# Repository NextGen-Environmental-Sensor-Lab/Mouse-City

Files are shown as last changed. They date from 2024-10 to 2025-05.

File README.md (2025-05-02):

# Mouse-City
Welcome to the NextGen Environmental Sensor Lab's Mouse City. We aim to simulate a city environment using urban sounds and various light patterns. This repository is currently incomplete but feel free to use the information available.

For any questions and concerns please file an issue through the issue tab. We'll try to resolve the issue as soon as possible!

Mouse City's core circuit components are a WeMos D1 Mini and a Audio FX Sound Board (from Adafruit). Additional contents of the circuit can be found in the [BOM](https://github.com/NextGen-Environmental-Sensor-Lab/Mouse-City/blob/main/BOM.md)  above. The BOM of the full circuit is located there as well.

 

## Content
### Arduino
* Required Libraries and Boards
* Code Contents
### Audio Tracks
* Audio File Type
* Converter
### Mouse City Circuit 
* Parts List
### Node-Red
* Node Function and Use

## Arduino IDE
To use the code in the [Arduino](https://github.com/NextGen-Environmental-Sensor-Lab/Mouse-City/tree/main/Arduino/CityMouseLight_Sound) folder the user needs to install the Adafruit Neopixel library and the esp8266 (by ESP8266 Community) board manager.
Once installed the code can be used. 

Note: The board used from this board manager is the "WEMOS D1 MINI ESP32".

Also Note: Our code is a modified version of the Adafruit Neopixel strandtest example. This can be seen where we use the theaterchase function to rotate the lights around the LED strip.

Code Contents: Our code contains multiple functions to control audio, speaker volume, and LED strip function. 

Note: Our code only recognizes predetermined commands. Unknown commands will be ignored.
* Audio: Sound() Where each input calls the selected audio track to play. There are 4 pins available, but only 3 are in use here.
* Volume: Volume() Where each input increases of decreases the volume.
* LED Strip: theaterChase() Where each input decides the pattern of the LED Strip for about 20 seconds.

## Audio Tracks 
To use the Sound() function the Arduino Soundboard needs at least one audio track. These tracks must be wav files. If the files you intend to use are different you can convert them. The converter we used is [cloud convert](https://cloudconvert.com/mp3-to-wav). 

Note: The soundboard only accepts 8 or 16 bit wav files. (The higher the bit the better the audio sounds). Also mono files compared to stero files are smaller in size allowing for less storage consumption. 

## Mouse City Circuit 
### Parts List

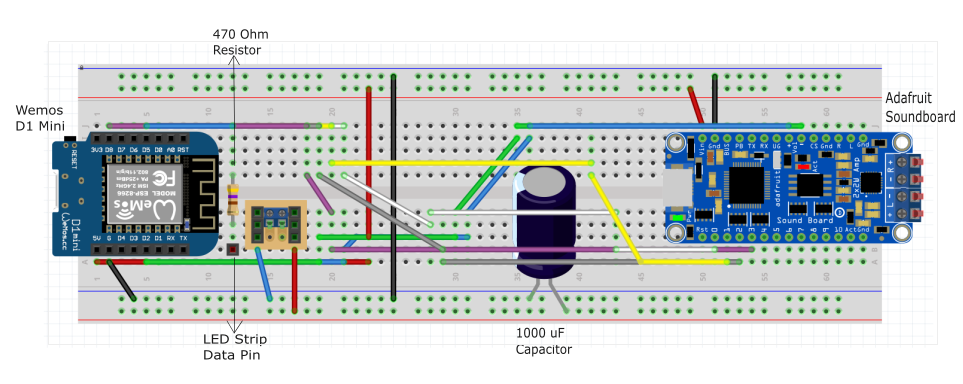
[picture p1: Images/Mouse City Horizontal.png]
 

| Part Name | Part Image | Purchase Link|
|---|---|:---:|
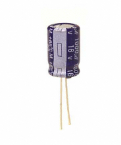
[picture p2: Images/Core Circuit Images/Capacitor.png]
|1000 µF Capacitor|  |[Digikey](https://www.digikey.com/en/products/detail/panasonic-electronic-components/ECA-1CM102B/8603353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)
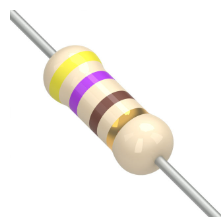
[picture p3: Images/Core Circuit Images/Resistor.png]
|470 Ohm Resistor|  |[Digikey](https://www.digikey.com/en/products/detail/koa-speer-electronics,-inc./CF1%2F4C471J/13537235?utm_adgroup=General&utm_source=google&utm_medium=cpc&utm_campaign=PMax%20Shopping_Product_Zombie%20SKUs&utm_term=&utm_content=General&utm_id=go_cmp-17815035045_adg-_ad-__dev-c_ext-_prd-13537235_sig-Cj0KCQjwjNS3BhChARIsAOxBM6pdZWOkhexXrhcUmCtDRSBonp6of6M5_js4P4ElzA45IlZfCEqIjtQaAlmEEALw_wcB&gad_source=1&gclid=Cj0KCQjwjNS3BhChARIsAOxBM6pdZWOkhexXrhcUmCtDRSBonp6of6M5_js4P4ElzA45IlZfCEqIjtQaAlmEEALw_wcB)
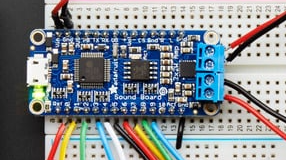
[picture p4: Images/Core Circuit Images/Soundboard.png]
|Adafruit Audio FX Sound Board|  |[Adafruit](https://www.adafruit.com/product/2217)
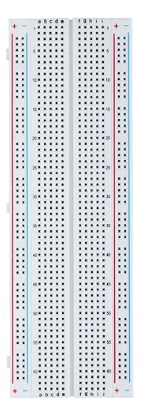
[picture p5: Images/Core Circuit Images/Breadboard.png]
|Breadboard|  |[Amazon](https://www.amazon.com/EL-CP-003-Breadboard-Solderless-Distribution-Connecting/dp/B01EV6LJ7G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)
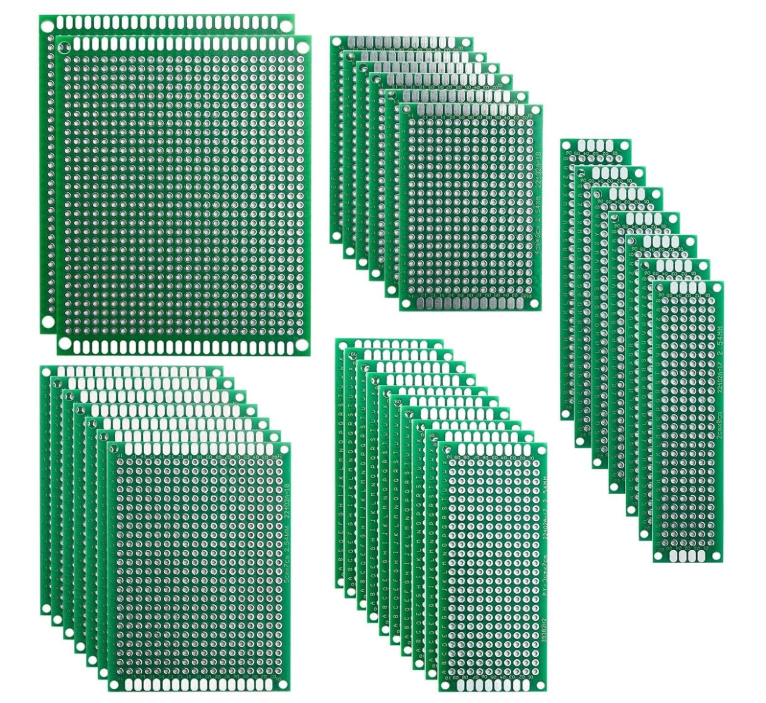
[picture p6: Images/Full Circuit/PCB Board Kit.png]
|ELEGOO PCB Board Kit|  |[Amazon](https://www.amazon.com/ELEGOO-Prototype-Soldering-Compatible-Arduino/dp/B072Z7Y19F)
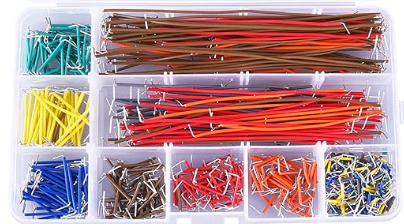
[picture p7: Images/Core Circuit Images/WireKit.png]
|Jumper Wire Kit|  |[Amazon](https://www.amazon.com/AUSTOR-Lengths-Assorted-Preformed-Breadboard/dp/B07CJYSL2T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)
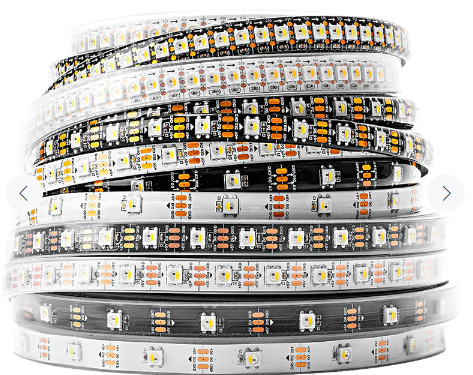
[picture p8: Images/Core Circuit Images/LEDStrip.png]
|LED Strip (White)|  |[BTF Lighting](https://www.btf-lighting.com/products/1-sk6812-rgbw-4-in-1-pixels-individual-addressable-led-strip-dc5v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)
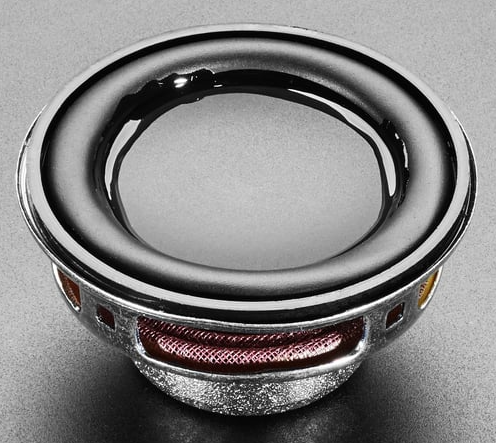
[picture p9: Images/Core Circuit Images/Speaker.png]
|Speaker - 40mm Diameter - 4 Ohm 5 Watt|  |[Adafruit](https://www.adafruit.com/product/3968)
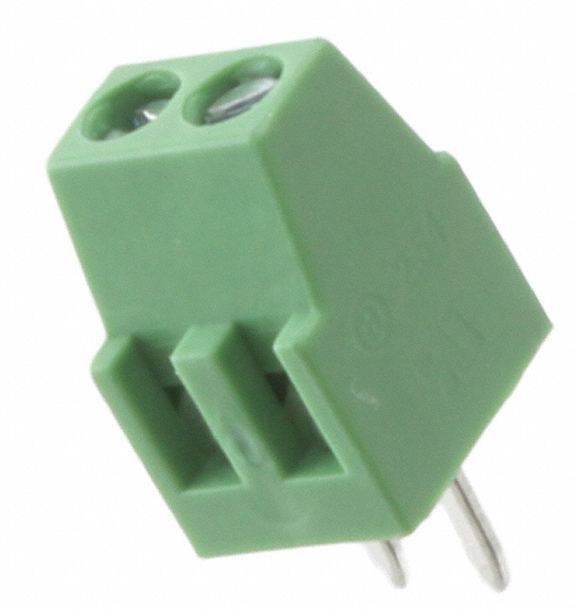
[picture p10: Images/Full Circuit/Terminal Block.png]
|Terminal Blocks|  |[Digikey](https://www.digikey.com/en/products/detail/qualtek/311007-01/183390)
|WeMos D1 Mini (Microcontroller)|  |[Amazon](https://www.amazon.com/dp/B0BR9GBNZH?ref=fed_asin_title)

### Important Note!!
Running the LED Strip and Voltage Supply through the bread board will cause a short circuit. To avoid this we suggest a spliced connection between the power supply, LED strip, and terminal block.

## Node-Red
Node-Red is a low-level coding program that visualizes code. We use it to automate the scheduling of our lights and audio. This was done through the use of different blocks of code Node-Red calls 'nodes'. The collection of these nodes are known as 'flows'.

Getting started with Node-Red. All information on setting up Node-Red can be found [here](https://nodered.org/docs/getting-started/) for new users.

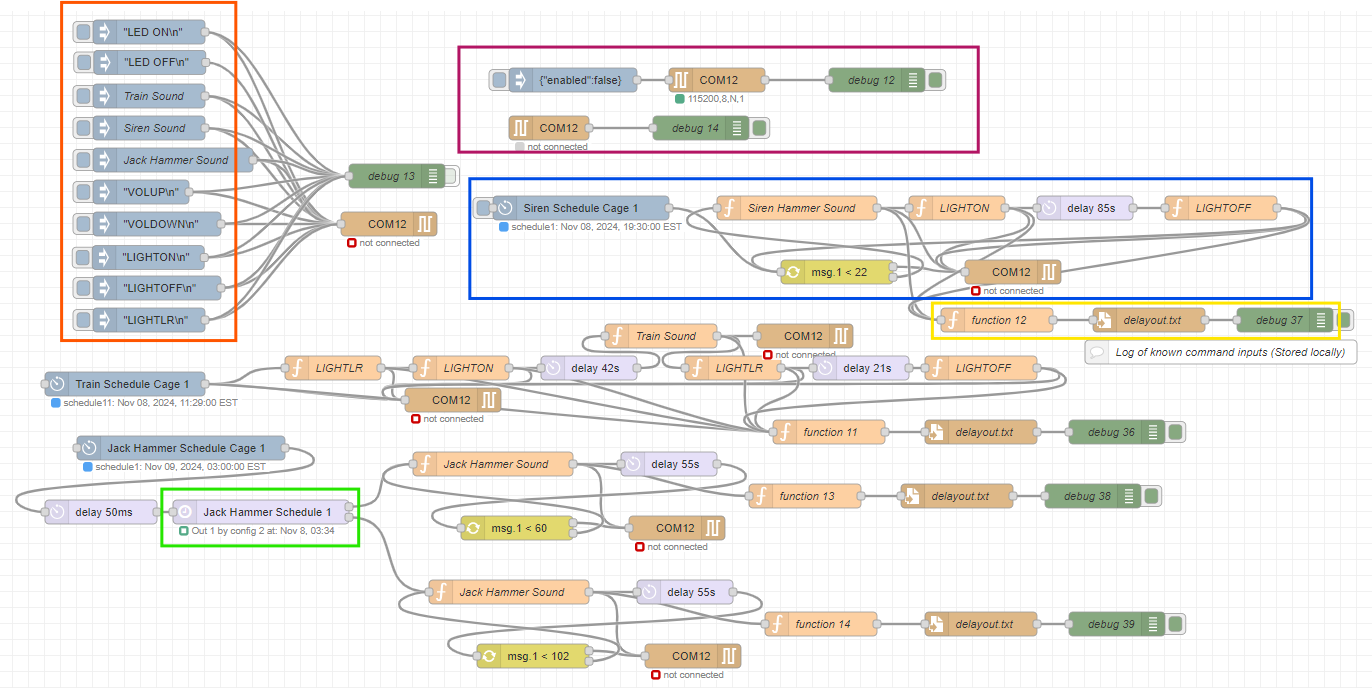
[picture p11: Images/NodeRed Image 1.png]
 

* Node Function:
    * The orange box displays all of the known commands our code will accept. These nodes inject/input the stated commands into the WeMos D1 Mini.
    
        Note: The commands for Sounds (Train, Siren, and Jack Hammer) are "PLAY0\n", "PLAY1\n", and "PLAY2\n" respectively. 
    * The purple box outputs information the serial port receives by use of the debug and serial port nodes. It also allows the user to disconnect from the serial port by injecting a "false".
    * The blue box contains the schedule for one of our audio tracks and lights. At a specified time set in the blue inject node (cronplus) the lights and sound play. The lights and sound are looped by the msg. node to play x amount of times that the user chooses.
    * The yellow box makes a local text file logging the inputs to the system.
    * The green box is a special scheduler (timegate) that allows two different action to take place based at the time they received.

Note: All NodeRed flows can be accessed [here](https://github.com/NextGen-Environmental-Sensor-Lab/Mouse-City/tree/main/Node%20Red%20Flows).

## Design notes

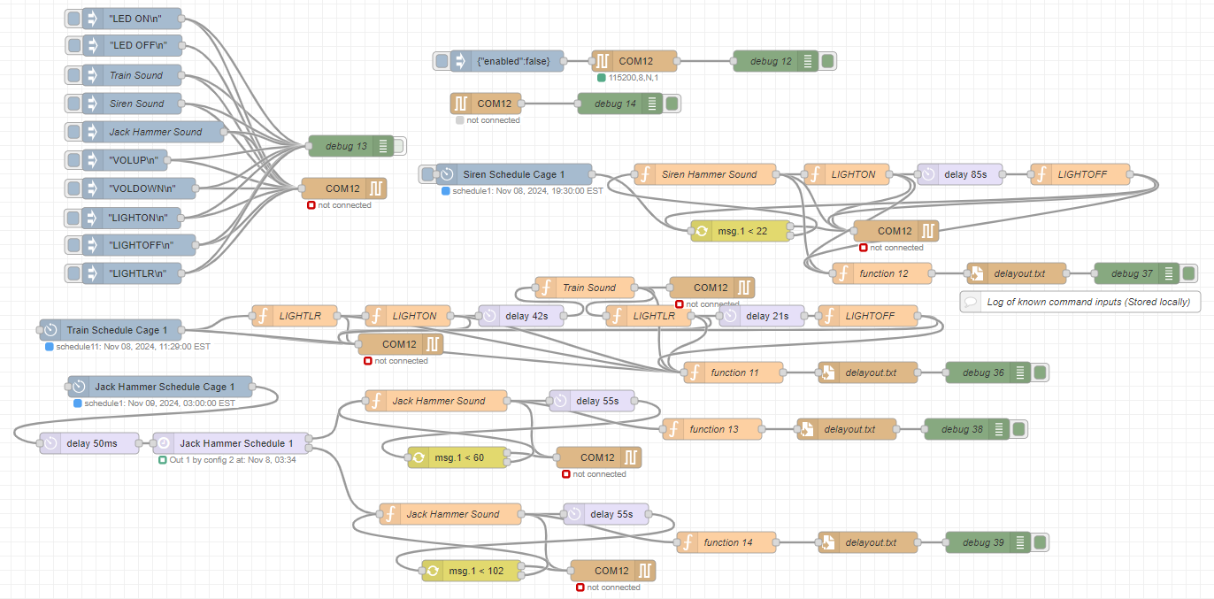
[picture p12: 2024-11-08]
Images/NodeRed Image 2.png

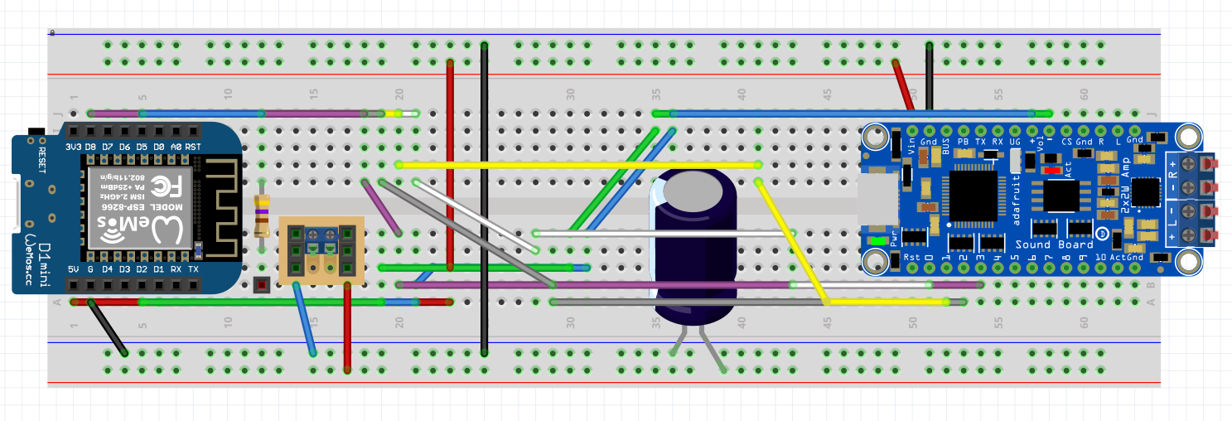
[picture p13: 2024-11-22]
Images/Mouse City Fritzing Horizontal.PNG

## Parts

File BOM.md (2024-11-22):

## Mouse City Complete  Build of Materials

| Product Name | Product | Purchase Link|
|---|---|:---:|
|1000 µF Capacitor|  |[Digikey](https://www.digikey.com/en/products/detail/panasonic-electronic-components/ECA-1CM102B/8603353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)
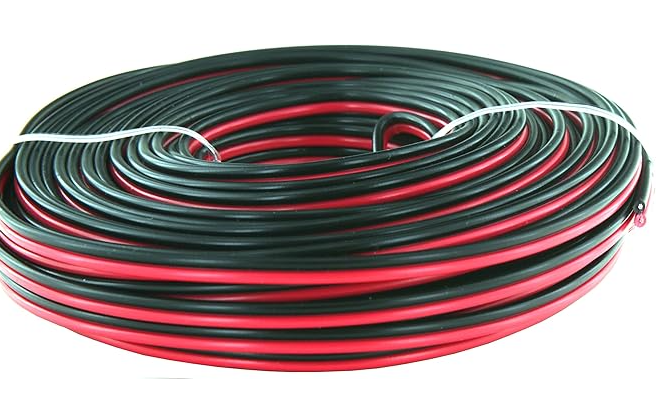
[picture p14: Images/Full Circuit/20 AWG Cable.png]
|2-Connector 20AWG Cable |  |[Amazon](https://www.amazon.com/American-Gauge-Copper-Wire/dp/B0791B4ZRW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)
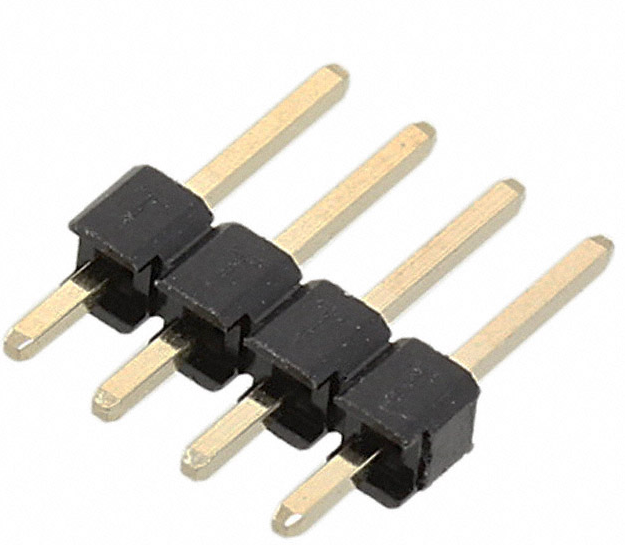
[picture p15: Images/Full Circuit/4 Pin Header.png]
|4 Pin Headers|  |[DigiKey](https://www.digikey.com/en/products/detail/w%C3%BCrth-elektronik/61300411121/4846827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)
|470 Ohm Resistor|  |[Digikey](https://www.digikey.com/en/products/detail/koa-speer-electronics,-inc./CF1%2F4C471J/13537235?utm_adgroup=General&utm_source=google&utm_medium=cpc&utm_campaign=PMax%20Shopping_Product_Zombie%20SKUs&utm_term=&utm_content=General&utm_id=go_cmp-17815035045_adg-_ad-__dev-c_ext-_prd-13537235_sig-Cj0KCQjwjNS3BhChARIsAOxBM6pdZWOkhexXrhcUmCtDRSBonp6of6M5_js4P4ElzA45IlZfCEqIjtQaAlmEEALw_wcB&gad_source=1&gclid=Cj0KCQjwjNS3BhChARIsAOxBM6pdZWOkhexXrhcUmCtDRSBonp6of6M5_js4P4ElzA45IlZfCEqIjtQaAlmEEALw_wcB)
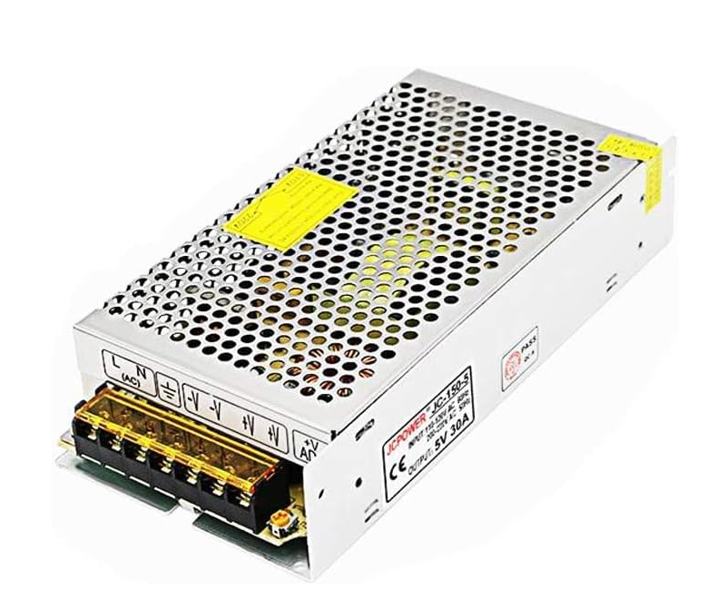
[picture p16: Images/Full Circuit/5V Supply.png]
|5V Power Supply |  |[Amazon](https://www.amazon.com/Universal-Regulated-Switching-Converter-Transformer/dp/B07PRY73TN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)
|Adafruit Audio FX Sound Board|  |[Adafruit](https://www.adafruit.com/product/2217)
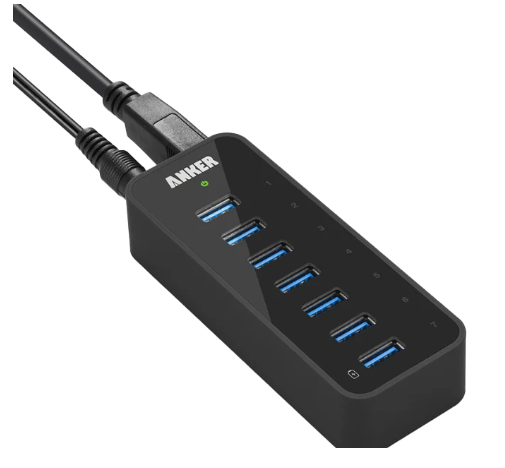
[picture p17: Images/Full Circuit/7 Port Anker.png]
|Anker 7-Port USB 3.0 Hub (USB Hub)|  |[Anker](https://www.anker.com/products/a7505?ref=search_result_anker%207-port%20usb%203.0%20hub&variant=37437048029334)
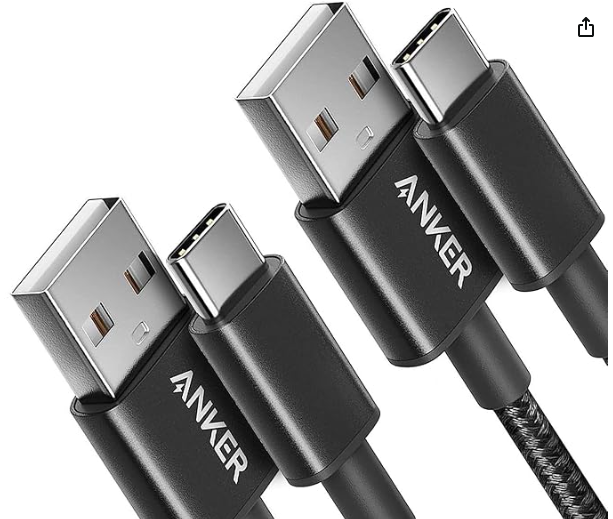
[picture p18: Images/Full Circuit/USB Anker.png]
|Anker USB to USB C Cable (USB Cable)|  |[Amazon](https://www.amazon.com/dp/B07DD5YHMH?ref=fed_asin_title)
|Breadboard|  |[Amazon](https://www.amazon.com/EL-CP-003-Breadboard-Solderless-Distribution-Connecting/dp/B01EV6LJ7G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)
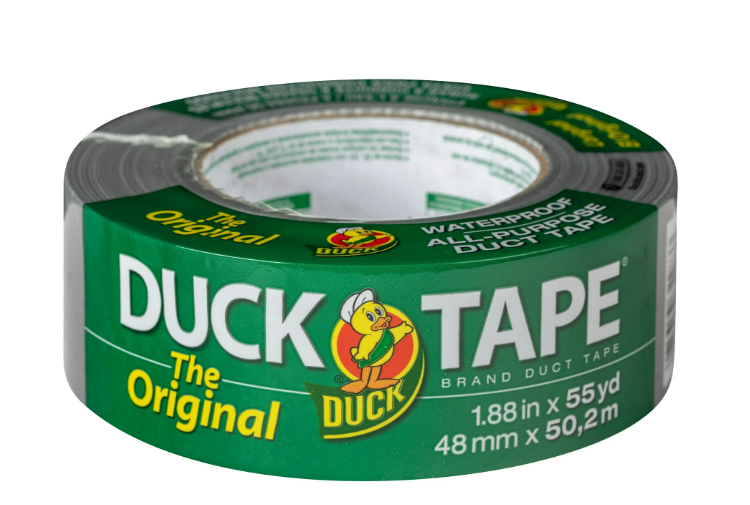
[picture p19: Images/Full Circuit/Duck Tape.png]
|Duck Tape|  |[Walmart](https://www.walmart.com/ip/Duck-Brand-1-88-in-x-55-yd-Silver-Original-Duct-Tape/591736470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)
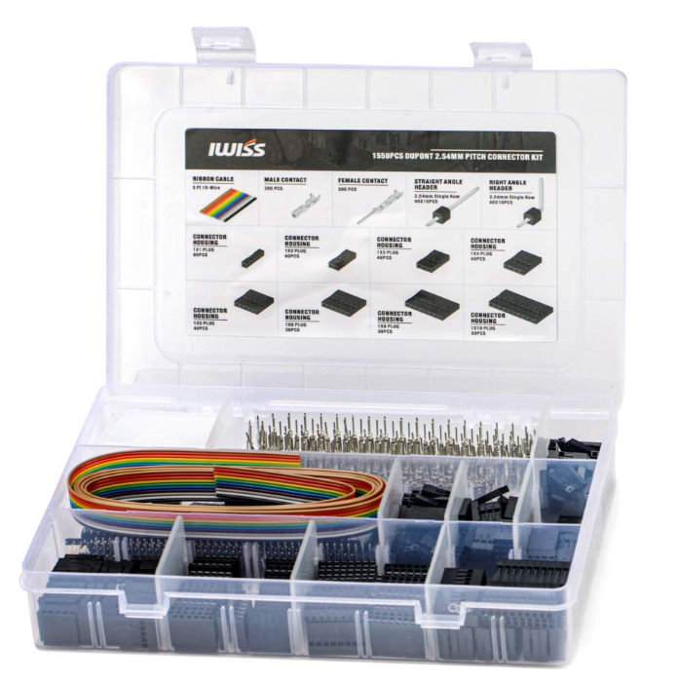
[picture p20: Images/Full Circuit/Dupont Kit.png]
|Dupont Connector Kit|  |[Amazon](https://www.amazon.com/IWISS-1550PCS-Connector-Headers-Balancer/dp/B08X6C7PZM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)
|ELEGOO PCB Board Kit|  |[Amazon](https://www.amazon.com/ELEGOO-Prototype-Soldering-Compatible-Arduino/dp/B072Z7Y19F)
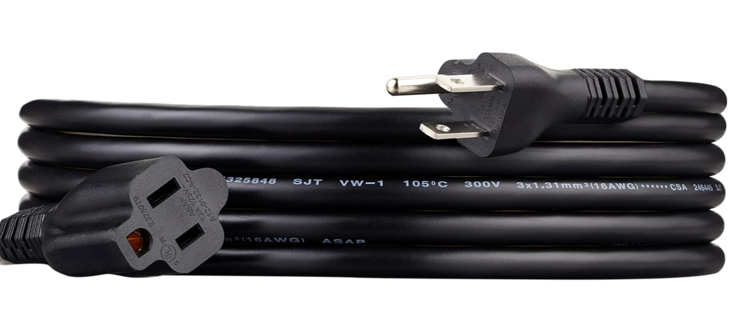
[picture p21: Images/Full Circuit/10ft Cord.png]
|Extentsion Cord (10 ft)|  |[Amazon](https://www.amazon.com/AmazonBasics-Extension-Cord-feet-Black/dp/B075BMVZ2N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)
|Heat Shrink Tubing Kit|  |[Amazon](https://www.amazon.com/Ginsco-580-pcs-Assorted-Sleeving/dp/B01MFA3OFA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)
|Jumper Wire Kit|  |[Amazon](https://www.amazon.com/AUSTOR-Lengths-Assorted-Preformed-Breadboard/dp/B07CJYSL2T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)
|OCR JST SM Connector Kit|  |[Amazon](https://www.amazon.com/OCR-Connector-Housing-Assortment-560Pcs-Set/dp/B071HFPXBD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)
|LED Strip (White)|  |[BTF Lighting](https://www.btf-lighting.com/products/1-sk6812-rgbw-4-in-1-pixels-individual-addressable-led-strip-dc5v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)
|Ribbon Cable(s)|  |[Amazon](https://www.amazon.com/Elegoo-EL-CP-004-Multicolored-Breadboard-arduino/dp/B01EV70C78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)
|Spade Connector Kit (Power Supply Connectors)|  |[Amazon](https://www.amazon.com/Tnisesm-Connector-Connectors-Terminals-Electrical/dp/B0CPHVHVSX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)
|Speaker - 40mm Diameter - 4 Ohm 5 Watt|  |[Adafruit](https://www.adafruit.com/product/3968)
|Terminal Blocks|  |[Digikey](https://www.digikey.com/en/products/detail/qualtek/311007-01/183390)
|Three Prong Power Cable (Power Supply Cable)|  |[Digikey](https://www.digikey.com/en/products/detail/on-shore-technology-inc/OSTVN02A150/1588862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)
|WeMos D1 Mini (Microcontroller)|  |[Amazon](https://www.amazon.com/dp/B0BR9GBNZH?ref=fed_asin_title)

## Mouse City Circuit Build of Materials

| Product Name | Product | Purchase Link|
|---|---|:---:|
|1000 µF Capacitor|  |[Digikey](https://www.digikey.com/en/products/detail/panasonic-electronic-components/ECA-1CM102B/8603353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)
|470 Ohm Resistor|  |[Digikey](https://www.digikey.com/en/products/detail/koa-speer-electronics,-inc./CF1%2F4C471J/13537235?utm_adgroup=General&utm_source=google&utm_medium=cpc&utm_campaign=PMax%20Shopping_Product_Zombie%20SKUs&utm_term=&utm_content=General&utm_id=go_cmp-17815035045_adg-_ad-__dev-c_ext-_prd-13537235_sig-Cj0KCQjwjNS3BhChARIsAOxBM6pdZWOkhexXrhcUmCtDRSBonp6of6M5_js4P4ElzA45IlZfCEqIjtQaAlmEEALw_wcB&gad_source=1&gclid=Cj0KCQjwjNS3BhChARIsAOxBM6pdZWOkhexXrhcUmCtDRSBonp6of6M5_js4P4ElzA45IlZfCEqIjtQaAlmEEALw_wcB)
|Adafruit Audio FX Sound Board|  |[Adafruit](https://www.adafruit.com/product/2217)
|Breadboard|  |[Amazon](https://www.amazon.com/EL-CP-003-Breadboard-Solderless-Distribution-Connecting/dp/B01EV6LJ7G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)
|ELEGOO PCB Board Kit|  |[Amazon](https://www.amazon.com/ELEGOO-Prototype-Soldering-Compatible-Arduino/dp/B072Z7Y19F)
|Jumper Wire Kit|  |[Amazon](https://www.amazon.com/AUSTOR-Lengths-Assorted-Preformed-Breadboard/dp/B07CJYSL2T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)
|LED Strip (White)|  |[BTF Lighting](https://www.btf-lighting.com/products/1-sk6812-rgbw-4-in-1-pixels-individual-addressable-led-strip-dc5v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)
|Speaker - 40mm Diameter - 4 Ohm 5 Watt|  |[Adafruit](https://www.adafruit.com/product/3968)
|Terminal Blocks|  |[Digikey](https://www.digikey.com/en/products/detail/qualtek/311007-01/183390)
|WeMos D1 Mini (Microcontroller)|  |[Amazon](https://www.amazon.com/dp/B0BR9GBNZH?ref=fed_asin_title)

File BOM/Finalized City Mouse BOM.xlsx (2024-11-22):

Product Name | Product Code | Purchase Date | Quantity | Price | Purchase Link
1000 µF Capacitor | ECA-1CM102B | 2024-10-03 | 4 | $2.44 | https://www.digikey.com/en/products/detail/panasonic-electronic-components/ECA-1CM102B/8603353?gad_source=1
2-Connector 20AWG Cable |  | 2021-11-15 | 1 | $18.80 | https://www.amazon.com/American-Gauge-Copper-Wire/dp/B0791B4ZRW?hvadid=694985735723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
4 Pin Headers | 61300411121 | N/A | 10 | $1.63 | https://www.digikey.com/en/products/detail/w%C3%BCrth-elektronik/61300411121/4846827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
470 Ohm Resistor | CF1/4C471J | N/A | 4 | $0.72 | https://www.digikey.com/en/products/detail/koa-speer-electronics,-inc./CF1%2F4C471J/13537235?gad_source=1
5V Power Supply |  | N/A | 1 | 18.99 | https://www.amazon.com/Universal-Regulated-Switching-Converter-Transformer/dp/B07PRY73TN?hvadid=692875362841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
Adafruit Audio FX Sound Board | 2217 | 2024-09-06 | 4 | $119.96 | https://www.adafruit.com/product/2217
Anker 7-Port USB 3.0 Hub (USB Hub) |  | 2024-08-26 | 1 | $39.99 | https://www.anker.com/products/a7505?variant=37437048029334
Anker USB to USB C Cable (USB Cable) |  | 2024-09-10 | 4 | $39.96 | https://www.amazon.com/dp/B07DD5YHMH?ref=fed_asin_title
Breadboard |  | N/A | 4 | $51.96 | https://www.amazon.com/EL-CP-003-Breadboard-Solderless-Distribution-Connecting/dp/B01EV6LJ7G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
Duck Tape |  | N/A | 1 | $4.98 | https://www.walmart.com/ip/Duck-Brand-1-88-in-x-55-yd-Silver-Original-Duct-Tape/591736470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
Dupont Connector Kit |  | N/A | 1 | $14.99 | https://www.amazon.com/IWISS-1550PCS-Connector-Headers-Balancer/dp/B08X6C7PZM
ELEGOO PCB Board Kit |  |  | 1 | $11.99 | https://www.amazon.com/ELEGOO-Prototype-Soldering-Compatible-Arduino/dp/B072Z7Y19F
Extentsion Cord (10 ft) |  | N/A | 1 | $9.99 | https://www.amazon.com/AmazonBasics-Extension-Cord-feet-Black/dp/B075BMVZ2N?hvadid=694786293255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
Heat Shrink Tubing Kit |  | N/A | 1 | $5.98 | https://www.amazon.com/Ginsco-580-pcs-Assorted-Sleeving/dp/B01MFA3OFA
Jumper Wire Kit |  | N/A | 1 | $11.99 | https://www.amazon.com/AUSTOR-Lengths-Assorted-Preformed-Breadboard/dp/B07CJYSL2T?s=industrial
LED Strip (White) |  | 2024-09-13 | 4 | $91.96 | https://www.btf-lighting.com/products/1-sk6812-rgbw-4-in-1-pixels-individual-addressable-led-strip-dc5v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
OCR JST SM Connector Kit |  | N/A | 1 | $11.86 | https://www.amazon.com/OCR-Connector-Housing-Assortment-560Pcs-Set/dp/B071HFPXBD
Ribbon Cable |  | N/A | 1 | $9.99 | https://www.amazon.com/Elegoo-EL-CP-004-Multicolored-Breadboard-arduino/dp/B01EV70C78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
Spade Connector Kit (Power Supply Connectors) |  | N/A | 1 | $8.95 | https://www.amazon.com/Tnisesm-Connector-Connectors-Terminals-Electrical/dp/B0CPHVHVSX
Speaker - 40mm Diameter - 4 Ohm 5 Watt | 3968 | 2024-09-27 | 4 | $19.80 | https://www.adafruit.com/product/3968
Terminal Blocks | OSTVN02A150 |  | 10 | $5.99 | https://www.digikey.com/en/products/detail/on-shore-technology-inc/OSTVN02A150/1588862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
Three Prong Power Cable (Power Supply Cable) | 311007-01 | N/A | 1 | $3.37 | https://www.digikey.com/en/products/detail/qualtek/311007-01/183390
WeMos D1 Mini (Microcontroller) |  | 2024-08-10 | 10 | $269.90 | https://www.amazon.com/dp/B0BR9GBNZH?ref=fed_asin_title

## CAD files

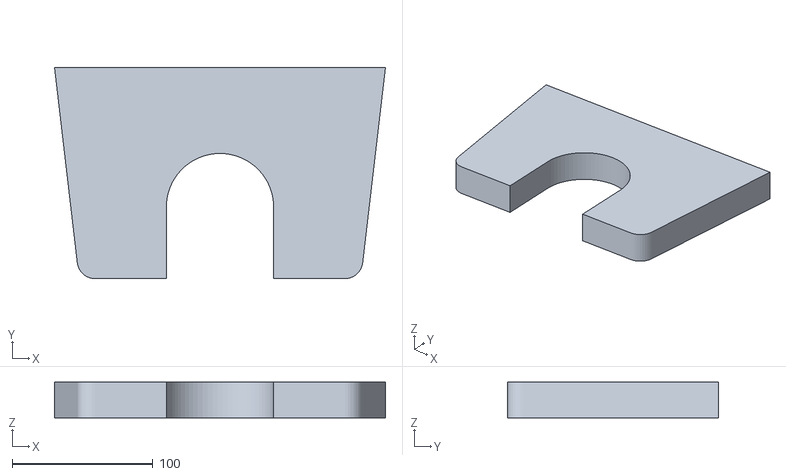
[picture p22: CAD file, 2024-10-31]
CAD/ASRC NeuroScience Mouse Experiment/Divider.stl
235.0 x 150.0 x 25.4

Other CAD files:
CAD/ASRC NeuroScience Mouse Experiment/Complete Divider.dwg
CAD/ASRC NeuroScience Mouse Experiment/Divider_Short.dwg
CAD/ASRC NeuroScience Mouse Experiment/Lid_Divider.dwg
CAD/ASRC NeuroScience Mouse Experiment/Lid_Divider (Ricardo Toledo-Crow's conflicted copy 2024-10-17).dwg
CAD/ASRC NeuroScience Mouse Experiment/OldVersions/Complete Divider.0001.dwg
CAD/ASRC NeuroScience Mouse Experiment/OldVersions/Divider.0005.dwg
CAD/ASRC NeuroScience Mouse Experiment/OldVersions/Divider_Short.0001.dwg
CAD/ASRC NeuroScience Mouse Experiment/OldVersions/Lid_Divider.0008.dwg
CAD/ASRC NeuroScience Mouse Experiment/OldVersions/Lid_Divider.0006.dwg
CAD/ASRC NeuroScience Mouse Experiment/OldVersions/Divider.0003.dwg
CAD/ASRC NeuroScience Mouse Experiment/Complete Divider.iam
CAD/ASRC NeuroScience Mouse Experiment/Divider.dwg
CAD/ASRC NeuroScience Mouse Experiment/Divider.ipt
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

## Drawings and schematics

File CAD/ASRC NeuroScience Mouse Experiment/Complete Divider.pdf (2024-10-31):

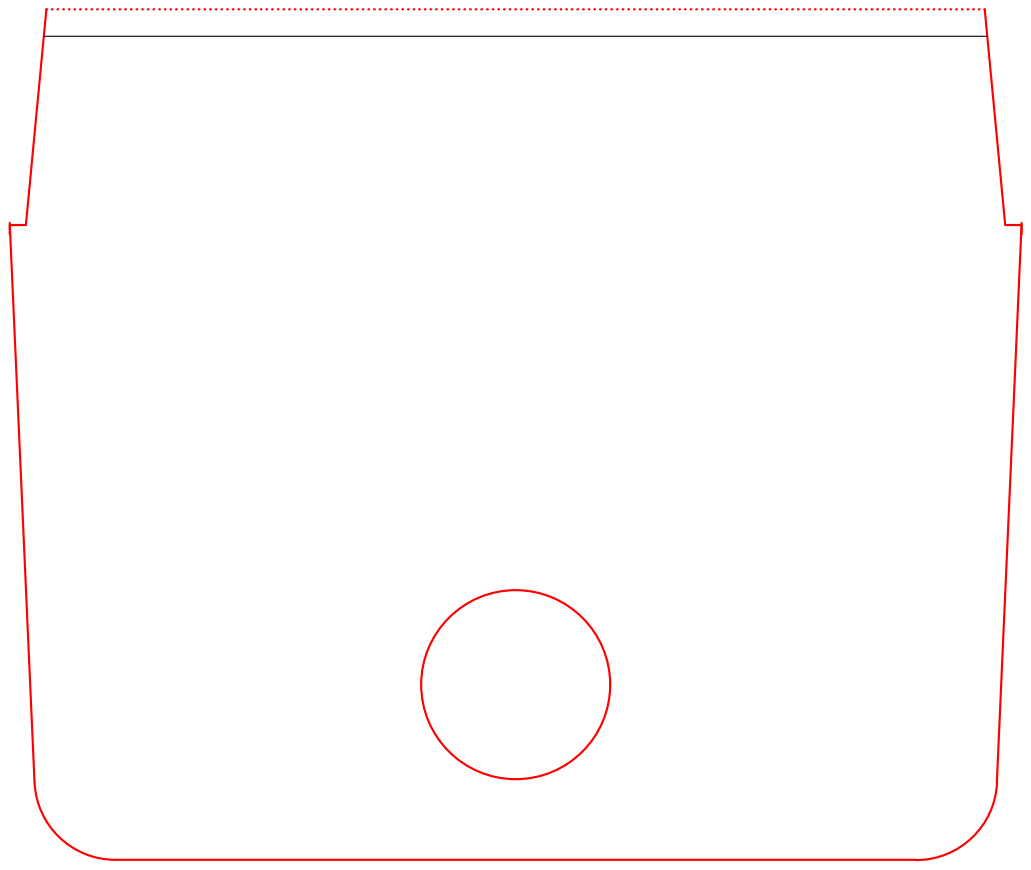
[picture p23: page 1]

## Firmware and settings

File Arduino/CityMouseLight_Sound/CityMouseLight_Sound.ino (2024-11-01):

// light and sound sketch for City Mouse experiment
// Gurleen Hothi, Ricardo Toledo-Crow, Mark Bellamy, ASRC CUNY, Sep 2024
// Flashes led strip and plays sound


#include <Adafruit_NeoPixel.h>

#define NPPIN D5       // Activation pin for Neopixels
#define WAVPIN D0      // Audio Track Pin
#define WAVPIN1 D6     //
#define WAVPIN2 D7     //
#define WAVPIN3 D8     // Extra Audio Track Pin Not Used
#define VOLUP D1       //  Volume Up Pin
#define VOLDOWN D2     //  Volume Down Pin
#define VOL_LIMIT 100  // Volume Limit
#define NUMPIXELS 144  // NeoPixel strip size
#define DELAYVAL 100   // Time (in milliseconds) to pause between pixels


String inputString = "";
bool stringComplete = false;

Adafruit_NeoPixel pixels(NUMPIXELS, NPPIN, NEO_GRBW + NEO_KHZ800);

void setup() {
  Serial.begin(115200);
  delay(8000);
  Serial.println(__FILE__);

  // Set wavpins and volume pins to 3.3V
  pinMode(WAVPIN, OUTPUT);
  digitalWrite(WAVPIN, HIGH);

  pinMode(WAVPIN1, OUTPUT);
  digitalWrite(WAVPIN1, HIGH);

  pinMode(WAVPIN2, OUTPUT);
  digitalWrite(WAVPIN2, HIGH);

  pinMode(WAVPIN3, OUTPUT);
  digitalWrite(WAVPIN3, HIGH);

  pinMode(VOLDOWN, OUTPUT);
  digitalWrite(VOLDOWN, HIGH);

  pinMode(VOLUP, OUTPUT);
  digitalWrite(VOLUP, HIGH);

  pixels.begin();  // INITIALIZE NeoPixel strip (REQUIRED)
  pixels.show();   // Initialize all pixels to 'off'

  inputString.reserve(200);
  pinMode(LED_BUILTIN, OUTPUT);
  Serial.println("Enter Commands :");  //Reserves 200 bits of memory
}

void loop() {
  while (Serial.available()) {
    char inChar = (char)Serial.read();  //Continuously reads input for commands
    inputString += inChar;
    if (inChar == '\n') {
      stringComplete = true;
      Serial.print(inputString);
    }

    if (stringComplete) {
      parseCommand(inputString);
      inputString = "";
      stringComplete = false;  // Passes completed string
    }
  }
}

// Remove any trailing newline or carriage return characters
void parseCommand(String command) {

  command.trim();

  // Check for specific commands and execute accordingly
  if (command == "LED ON") {
    digitalWrite(LED_BUILTIN, LOW);
    Serial.println("LED turned ON");
  } else if (command == "LED OFF") {
    digitalWrite(LED_BUILTIN, HIGH);
    Serial.println("LED turned OFF");
  } else if (command.startsWith("SET PWM ")) {
    // Example command: SET PWM 128
    int pwmValue = command.substring(8).toInt();  // Extract the value after "SET PWM "
    analogWrite(LED_BUILTIN, pwmValue);
    Serial.print("PWM set to: ");
    Serial.println(pwmValue);  //?
  } else if (command.startsWith("PLAY0")) {
    // execute Sound()
    Sound(WAVPIN);
  } else if (command.startsWith("PLAY1")) {
    Sound(WAVPIN1);
  } else if (command.startsWith("PLAY2")) {
    Sound(WAVPIN2);
  } else if (command.startsWith("LIGHTON")) {
    // execute lighton()
    lighton(WAVPIN2);
  } else if (command.startsWith("LIGHTOFF")) {
    // execute lightoff()
    lightoff(WAVPIN2);
  } else if (command.startsWith("LIGHTLR")) {
    // execute lightLR()
    lightLR(WAVPIN2);
  } else if (command.startsWith("VOLUP")) {
    // execute Volume()
    Volume(VOLUP);
  } else if (command.startsWith("VOLDOWN")) {
    // execute Volume()
    Volume(VOLDOWN);
  } else {
    // Handle unknown commands
    Serial.print("Unknown command: ");
    Serial.println(command);
  }
}

// turn off all pixels
void lightoff(int wav) {
  pixels.clear();
  pixels.show();
}

// turn on all pixels to max values
void lighton(int wav) {
  static uint32_t maxWhite = pixels.Color(255, 255, 255, 255);
  for (int c = 0; c < pixels.numPixels(); c++) {
    pixels.setPixelColor(c, maxWhite);  // Set pixel 'c' to value 'color'
  }
  pixels.show();
}

// move pixels left to right three pixels every move
void lightLR(int wav) {
  theaterChase(pixels.Color(255, 255, 255, 255), 6, 52);
  pixels.show();
  pixels.clear();
}

// start track audio
void Sound(int wav) {
  pinMode(wav, OUTPUT);
  digitalWrite(wav, LOW);
  delay(300);
  digitalWrite(wav, HIGH);
}

//Adjust speaker volume
void Volume(int updown) {
  // start sound
  pinMode(updown, OUTPUT);
  for (int i = 0; i < VOL_LIMIT; i++) {
    digitalWrite(updown, LOW);
    delay(50);
    digitalWrite(updown, HIGH);
    delay(50);
    digitalWrite(updown, LOW);
    delay(50);
    digitalWrite(updown, HIGH);
  }
}

//light control
void theaterChase(uint32_t color, int gap, int wait) {
  for (int a = 0; a < 60; a++) {     //Repeat 60 times
    for (int b = 0; b < gap; b++) {  //'b' counts from 0 to 2
      pixels.clear();                //Set all pixels in RAM to 0 (off)

      // 'c' counts up from 'b' to the end of strip in steps of 3
      for (int c = b; c < pixels.numPixels(); c += gap) {
        pixels.setPixelColor(c, color);  // Set pixel 'c' to value 'color'
      }
      pixels.show();  // Update strip with new contents
      delay(wait);    // Pause for a moment
    }
  }
}

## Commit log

2024-10-31 Added Mouse City Folders
    Included Folders: Arduino Code, Audio Files, BOM, and CAD
    [Complete Divider.0001.dwg, Complete Divider.dwg, Complete Divider.iam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]
2024-10-31 Added the Node Red Folder
    Contains all flows for the four cages
2024-10-31 Removed Obsolete Folders/Files. Added a new NodeRed folder
    Removed Obsolete Folders/Files. Added a folder for NodeRed flow containing all cages.
2024-11-01 Updated NodeRed Flows and Arduino Code
    NodeRed: Organized folders and Added a command tracker linked to notepad file 'delayout'
    Arduino: Added comments and Renamed files
2024-11-01 Added a Fritzing Folder, Images Folder, made modifications to BOM and README
    Fritzing Folder of Mouse City Circuit
    Images Folder of Fritzing circuit
    Modified BOM (Circuit only materials) and README (Work in progress)
    [Finalized City Mouse BOM.xlsx, Mouse_City_Circuit.fzz]
2024-11-01 Update CityMouseLight_Sound.ino
    Updated Arduino code
2024-11-08 New Image, README Update
    Added a image of cage 1 node red flow. Updated README
2024-11-08 Updated README and BOM. Added images for core circuit parts
    Updated README and BOM. Added images for core circuit parts
    [Finalized City Mouse BOM.xlsx]
2024-11-14 BOM Markdown and Images
    Added a markdown file for BOM; added a folder off BOM images
2024-11-22 Made changes to the LED strip connection
    Due to a short circuit caused by the LED strip and power supply onto the bread board we changed the hardware. We implemented a terminal block on a PCB board that connects to the +/- terminals of the board board. The LED strip, power supply, and terminal block are connected through a 3 way splice.
    Overall resulting in changes to the BOM, Images, and READ.ME
    Note: Keyed Connecter usage changed to terminal block and JST connector use
    [Finalized City Mouse BOM.xlsx, Mouse_City_Circuit.fzz]
2024-11-22 Included missing Component
    [Finalized City Mouse BOM.xlsx]
2024-11-22 Removed Past Component
    [Finalized City Mouse BOM.xlsx]
